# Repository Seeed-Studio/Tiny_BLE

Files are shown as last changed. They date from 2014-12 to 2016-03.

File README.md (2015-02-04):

Tiny BLE
==========

The Tiny BLE is a Bluetooth Low Energy development board designed with low energy consumption and small size in mind. It's integrated with current measurement feature to provide real time energy consumption data, which is essential for developers to optimize software to design long battery life devices. It supports ARM mbed cloud-based IDE with an handy C/C++ SDK and a large number of open source libraries, which makes prototyping and development extremely easy. Further, to keep it small, we use modular design to enable it divide into two parts - CMSIS DAP interface part and BLE part.

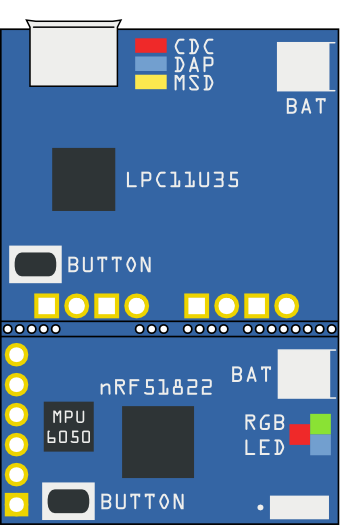
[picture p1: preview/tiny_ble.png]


----
### CMSIS DAP Interface Part
The interface is very powerful to provide features :

+ Drag-n-drop programming
+ CMSIS DAP debug
+ USB Virtual serial port
+ Current measurement
+ Battery charging

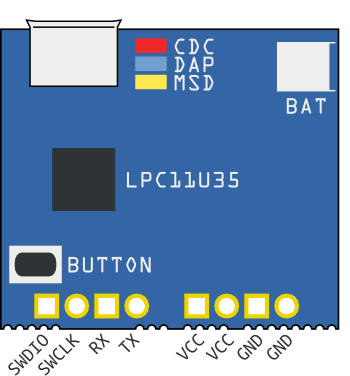
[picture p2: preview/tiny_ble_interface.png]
interface


To enable the current measurement feature, just set the baud rate of the USB virtual serial port to 4000000+, then the current data of the BLE part will be sent through the virtual serial port. To make data easier to use, we create a cross platform tool - BLE Smurfs Monitor to make it visual.

+ [Tiny BLE Monitor for Windows](http://tangram.qiniudn.com/ble_smurfs_monitor_v0.1.exe)
+ [Tiny BLE Monitor for Linux/Mac OS](https://github.com/Seeed-Studio/Tiny_BLE/tree/master/utils), additional requirements: pyqtgraph, pyside

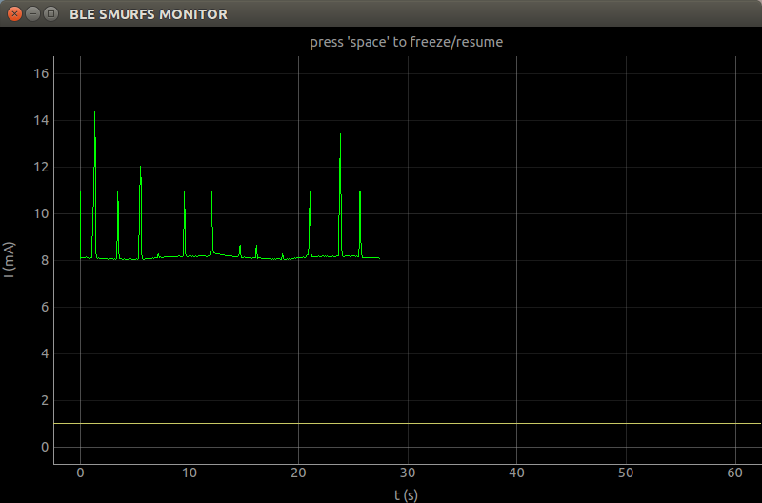
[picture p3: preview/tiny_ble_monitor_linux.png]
Tiny BLE Monitor


----

### BLE part

+ Nordic nRF51822 with BLE and ARM Cortex M0
+ MPU6050, 3d accelerometer and 3d gyroscope
+ RGB LED
+ Battery Connector & Battery Voltage Measurement
+ all 4 I/Os can be used as analog input, digital input/output, i2c, spi or uart

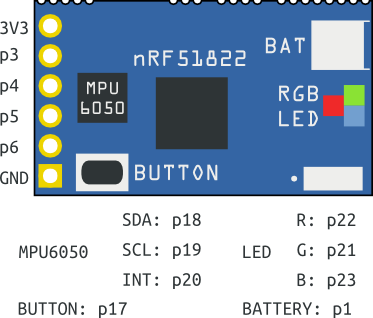
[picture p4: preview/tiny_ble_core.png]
ble part


The BLE part is built on the Nordic nRF51822 with Bluetooth Low Energy 2.4GHz multiprotocol radio and a 32 bit ARM Cortex-M0 core running 16MHz.
MPU6050, a 6 DOF with 3D accelerometer and 3D gyroscope, is integrated to provide motion detect feature. The Digital Motion Processor (DMP) of the MPU6050 provide several features (such as gesture detect, pedometer, calibrating gyro data) which
can reduce running time of the nRF51822 to get a long battery life. It also integrates battery connector and battery voltage measurement circuit for you.
We custom a bootloader for the BLE Smurfs to enable Firmware-Over-The-Air feature. when the BLE Smurfs is divided into two parts, we can still update the firmware of the nRF51822 through FOTA

Have fun!

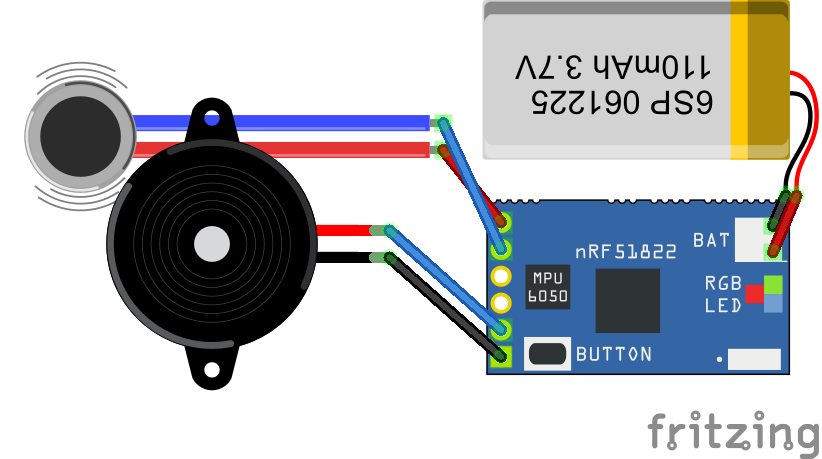
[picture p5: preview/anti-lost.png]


----

This software in this repository is written by [Seeedstudio](http://seeed.cc)<br>
and is licensed under [The Apache License V2.0](http://www.apache.org/licenses/LICENSE-2.0).

Contributing to this software is warmly welcomed. You can do this basically by<br>
[forking](https://help.github.com/articles/fork-a-repo), committing modifications and then [pulling requests](https://help.github.com/articles/using-pull-requests) (follow the links above<br>
for operating guide). Adding change log and your contact into file header is encouraged.<br>
Thanks for your contribution.

Seeed Studio is an open hardware facilitation company based in Shenzhen, China. <br>
Benefiting from local manufacture power and convenient global logistic system, <br>
we integrate resources to serve new era of innovation. Seeed also works with <br>
global distributors and partners to push open hardware movement.<br>

Analytics (https://github.com/igrigorik/ga-beacon)

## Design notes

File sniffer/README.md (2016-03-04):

Tiny BLE as a BLE Sniffer
=========================

1. Get nRF Sniffer resource from [Nordic Semiconductor](https://www.nordicsemi.com/eng/Products/Bluetooth-Smart-Bluetooth-low-energy/nRF-Sniffer)

2. download the firmware of nRF Sniffer into the Tiny BLE.

3. Replace the interface firmware of Tiny BLE  with the [usb_to_uart_firmware.bin](usb_to_uart_firmware.bin) file.

  As the USB virtual serial's performance of the default firmware is not good enough, we need replace a new firmware.

  a. hold the button of the Tiny BLE and plug it into your computer.
  b. replace the firmware.bin file of a disk named `CRP DISABLD` with the usb_to_uart_firmware.bin file. If Linux/Mac is used, use the`sudo dd if={/path/to/usb_to_uart_firmware.bin} of={/path/to/firmware.bin} conv=notrunc` command.
  c. re-plug it into the computer. If windows is used, install the usb_to_uart_driver.inf driver.

4. If windows is used, use the BLE Sniffer application from Nordic Semiconductor. If Mac OS X is used, [nrf-ble-sniffer-osx](https://sourceforge.net/projects/nrfblesnifferosx/) is good choice.

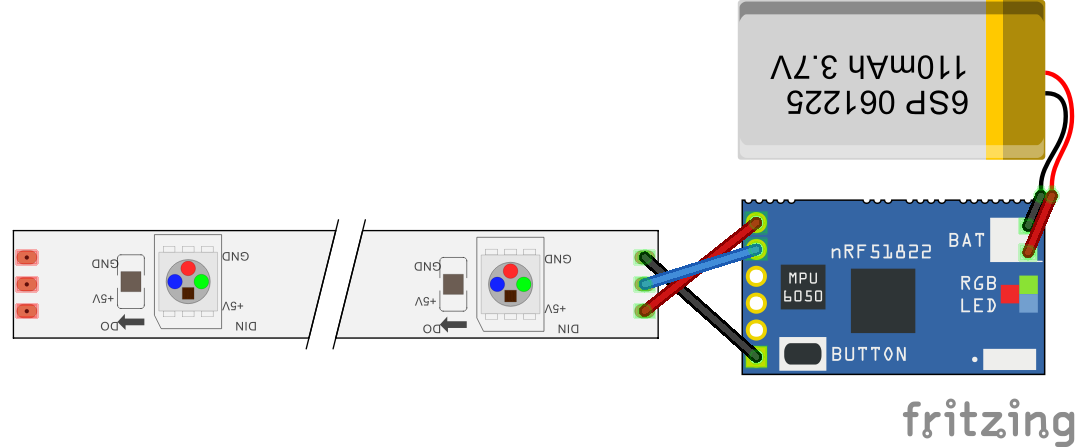
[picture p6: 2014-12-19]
preview/tiny_ble_color_pixels.png

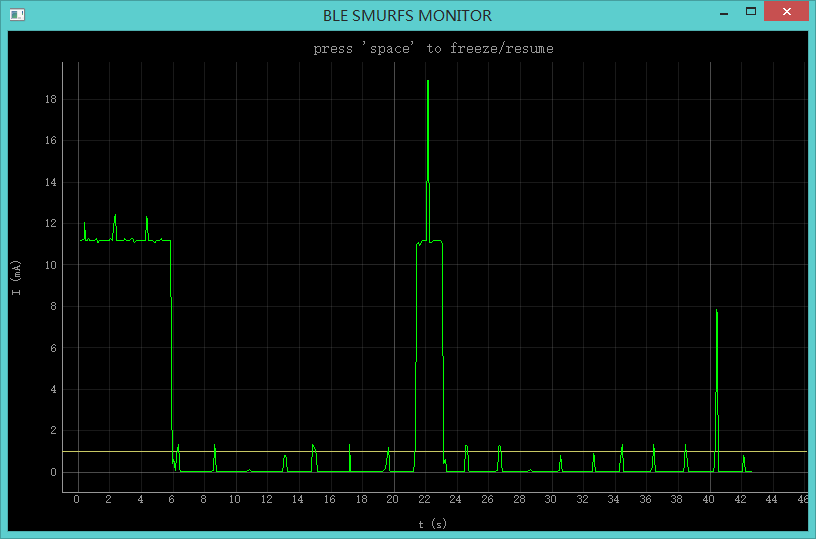
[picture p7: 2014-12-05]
preview/tiny_ble_monitor_windows.png

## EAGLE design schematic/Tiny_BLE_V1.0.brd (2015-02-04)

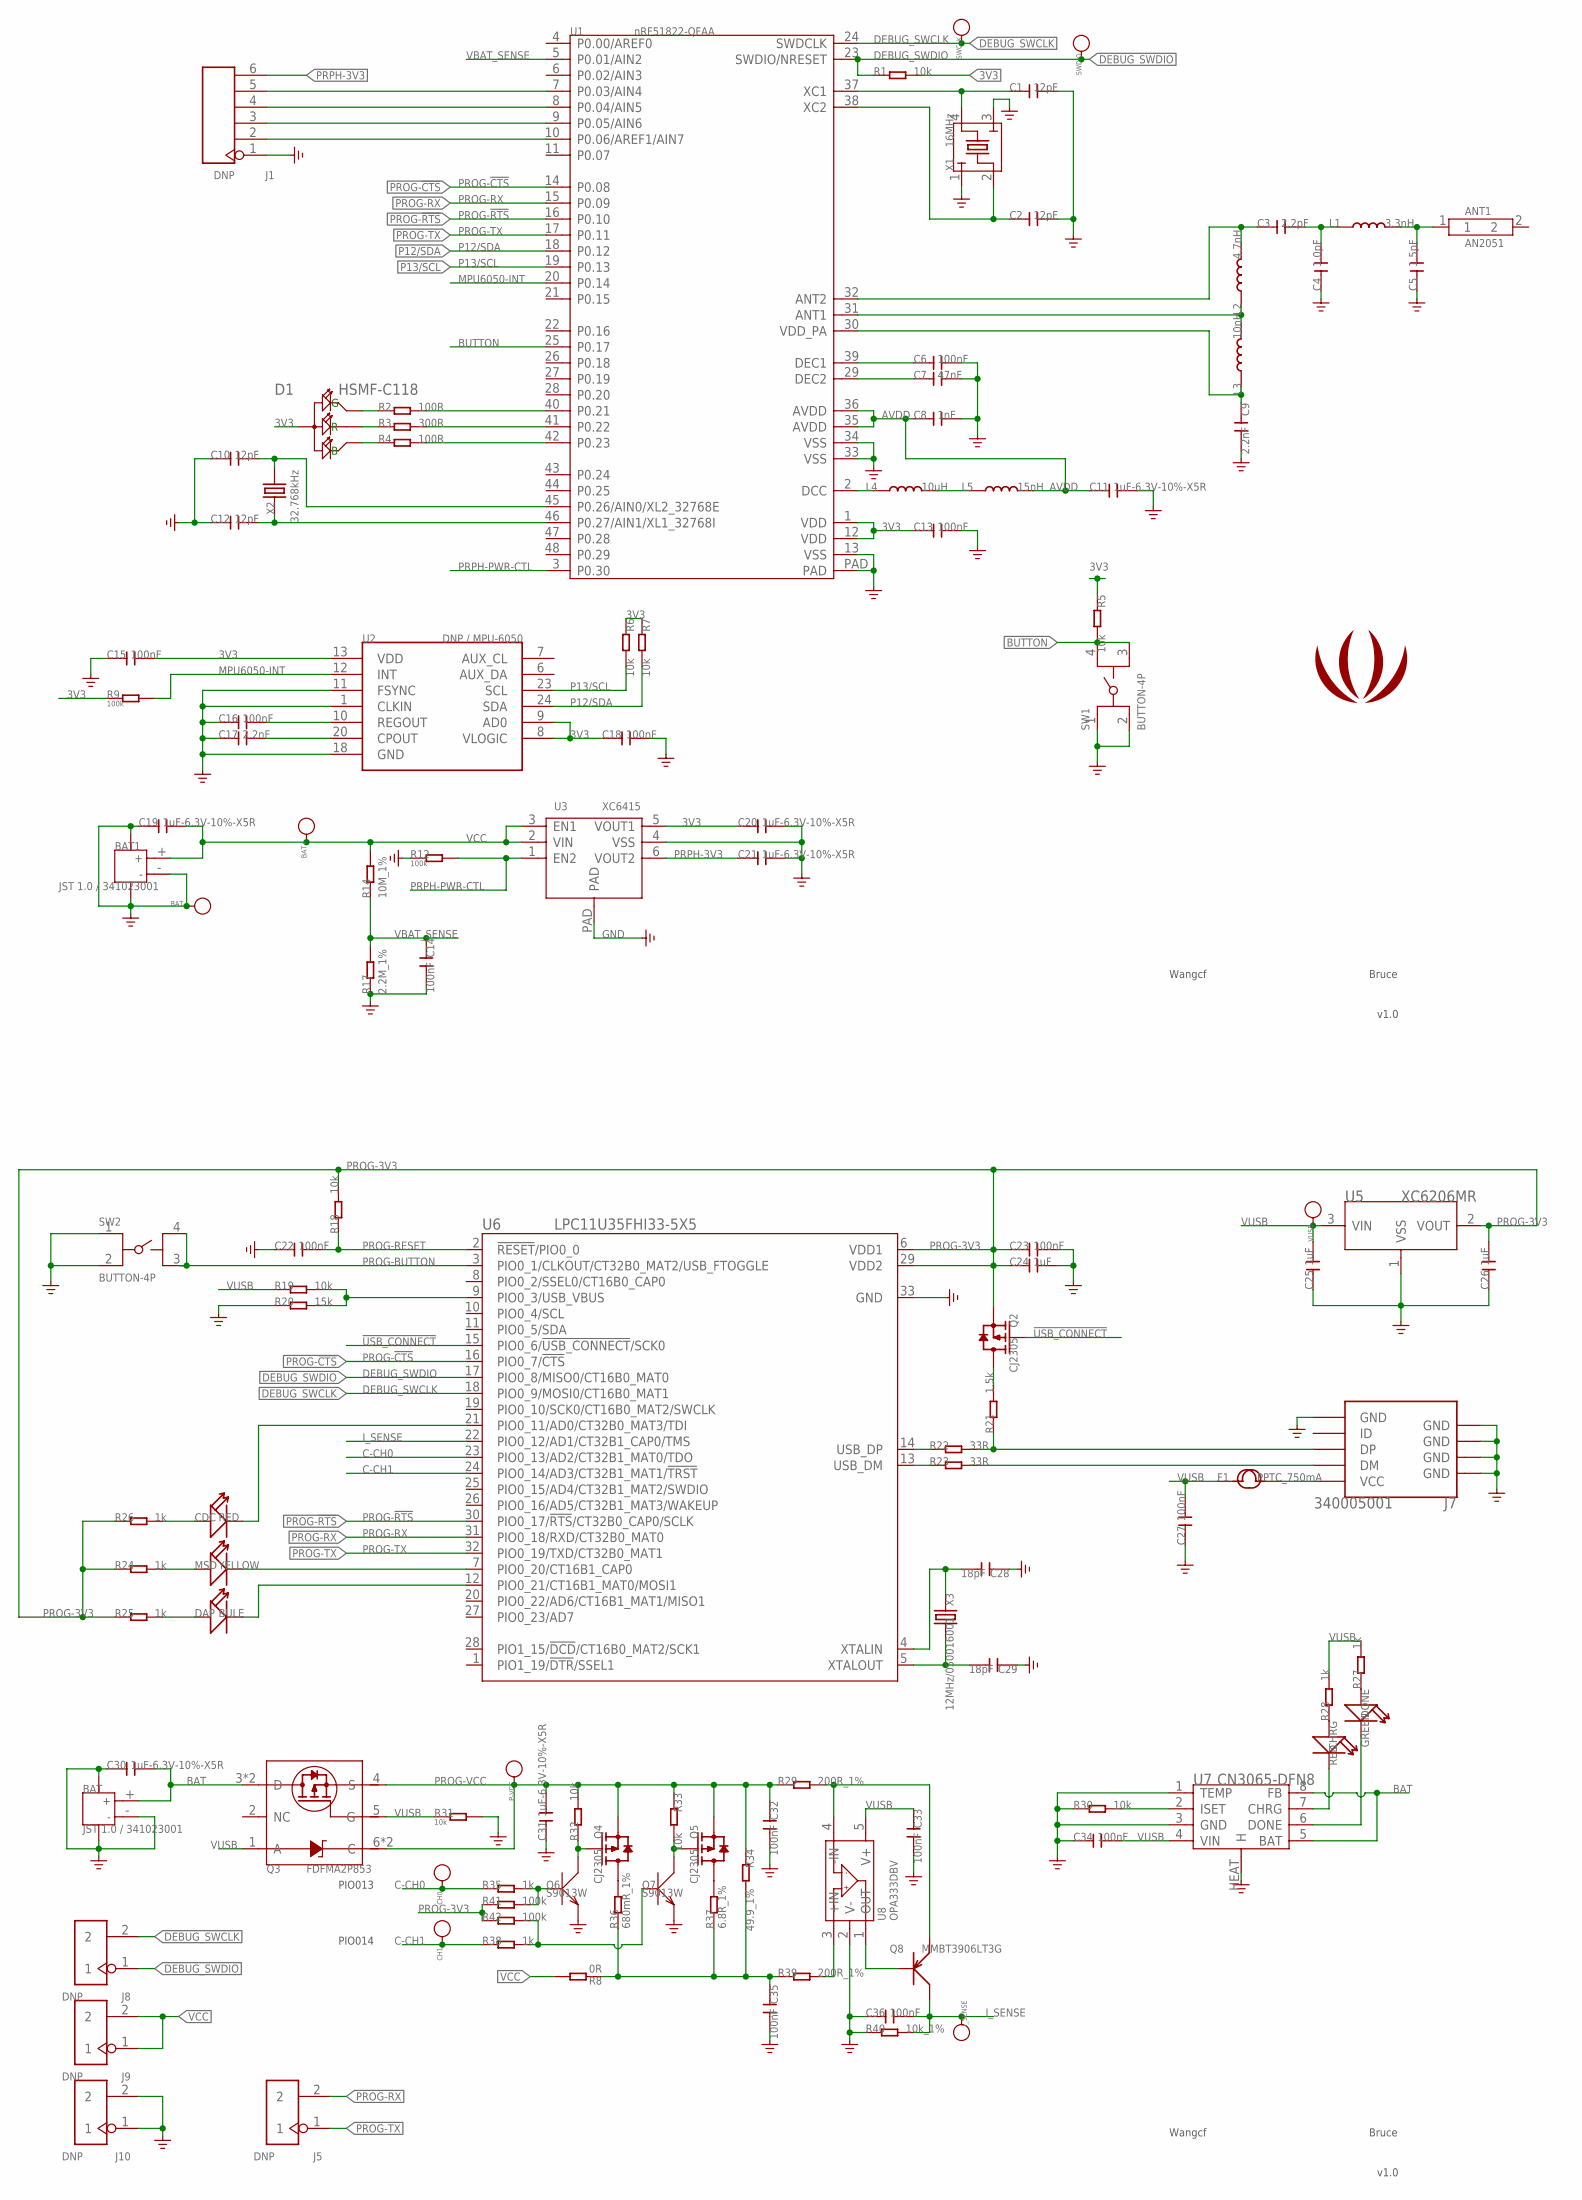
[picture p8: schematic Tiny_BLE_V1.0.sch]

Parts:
ANT1: AN2051; 2P-SMD-L5.05*W.02*H1.07MM
BAT, BAT1: JST 1.0 / 341023001; JST-SMD-2P-1.0-90D
BAT+: BAT+; PAD_4080
BAT-: BAT-; PAD_4080
C1, C2, C10, C12: 12pF; C0402
C3: 2.2pF; C0402
C4: 1.0pF; C0402
C5: 1.5pF; C0402
C6, C13, C14, C15, C16, C18, C22, C23, C27, C32, C33, C34, C35, C36: 100nF; C0402
C7: 47nF; C0402
C8: 1nF; C0402
C9, C17: 2.2nF; C0402
C11, C19, C20, C21, C30, C31: 1uF-6.3V-10%-X5R; C0402
C24, C25, C26: 1uF; C0402
C28, C29: 18pF; C0402
CDC: RED; LED-0603
CH0: CH0; TP_4545
CH1: CH1; TP_4545
CHRG: RED; LED-0603
D1: HSMF-C118; LED-4P-1210-3.0X2.54
DAP: BULE; LED-0603
DONE: GREEN; LED-0603
F1: PPTC_750mA; F1206
I_SENSE: I_SENSE; TP_4545
J1: DNP; 6P-2.54-60/35MIL
J5, J8, J9, J10: DNP; 2P-2.54-65/35MIL
J7: 340005001; MICRO-USB
L1: 3.3nH; L0402
L2: 4.7nH; L0402
L3: 10nH; L0402
L4: 10uH; L0603
L5: 15nH; L0402
MSD: YELLOW; LED-0603
P-VCC: P_VCC; TP_4545
Q2, Q4, Q5: CJ2305; SOT23
Q3: FDFMA2P853; 6P-SMD-W/-HEAT
Q6, Q7: S9013W; SOT323
Q8: MMBT3906LT3G; SOT23
R1, R5, R6, R7, R18, R19, R30, R31, R32, R33: 10k; R0402
R2, R4: 100R; R0402
R3: 300R; R0402
R8: 0R; R0603
R9, R12, R41, R42: 100k; R0402
R14: 10M_1%; R0402
R17: 2.2M_1%; R0402
R20: 15k; R0402
R21: 1.5k; R0402
R22, R23: 33R; R0402
R24, R25, R26, R27, R28, R35, R38: 1k; R0402
R29, R39: 200R_1%; R0402
R34: 49.9_1%; R0603
R36: 680mR_1%; R0603
R37: 6.8R_1%; R0603
R40: 10k_1%; R0402
SW1, SW2: BUTTON-4P; 4P-SMD-L4.45*W3.22*H2.5MM
SWCLK: SWDCLK; PAD_4080
SWDIO: SWDIO; PAD_4080
U1: nRF51822-QFAA; QFN48-6X6MM
U2: DNP / MPU-6050; QFN24
U3: XC6415; USP-6C
U5: XC6206MR; SOT23
U6: LPC11U35FHI33-5X5; HVQFN33
U7: CN3065-DFN8; DFN8
U8: OPA333DBV; SOT23-5
U$59: LOGO-SEEEDSTUDIO-SMALL-SILK; SMALL_SEEED_LOGO
VUSB: VUSB; TP_4545
X1: 16MHz; 2520
X2: 32.768kHz; 2P-SMD-3.2X1.5
X3: 12MHz/050016001; 2P-SMD-5X3.2

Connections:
3V3: C13.1, C15.2, C18.1, C20.1, D1.1 (+), R1.2, R5.1, R6.1, R7.1, R9.1, U1.1 (VDD), U1.12 (VDD), U2.8 (VLOGIC), U2.9 (AD0), U2.13 (VDD), U3.5 (VOUT1)
!USB_CONNECT: Q2.1 (G), U6.15 (PIO0_6/!USB_CONNECT!/SCK0)
AVDD: C8.1, C11.1, L5.2, U1.35 (AVDD), U1.36 (AVDD)
BAT: BAT.+ (1), C30.2, Q3.3 (D), Q3.P2 (D), U7.5 (BAT), U7.8 (FB)
BUTTON: R5.2, SW1.3, SW1.4, U1.25 (P0.17)
C-CH0: CH0.T, R35.1, U6.23 (PIO0_13/AD2/CT32B1_MAT0/TDO)
C-CH1: CH1.T, R38.1, U6.24 (PIO0_14/AD3/CT32B1_MAT1/!TRST!)
CHRG: CHRG.-, U7.7 (CHRG)
CHRG-DONE: DONE.-, U7.6 (DONE)
DCC: L4.1, U1.2 (DCC)
DEBUG_SWCLK: J8.2, SWCLK.1, U1.24 (SWDCLK), U6.18 (PIO0_9/MOSI0/CT16B0_MAT1)
DEBUG_SWDIO: J8.1, R1.1, SWDIO.1, U1.23 (SWDIO/NRESET), U6.17 (PIO0_8/MISO0/CT16B0_MAT0)
GND: BAT.3, BAT.4, BAT.- (2), BAT1.3, BAT1.4, BAT1.- (2), BAT-.1, C1.2, C2.2, C4.1, C5.1, C6.2, C7.2, C8.2, C9.2, C10.1, C11.2, C12.1, C13.2, C14.2, C15.1, C16.1, C17.1, C18.2, C19.1, C20.2, C21.2, C22.1, C23.2, C24.2, C25.1, C26.1, C27.1, C28.1, C29.1, C30.1, C31.1, C32.2, C33.2, C34.1, C35.2, C36.1, J1.1, J7.5 (GND), J7.S1 (GND), J7.S2 (GND), J7.S3 (GND), J7.S4 (GND), J7.S5 (GND), J7.S6 (GND), J10.1, J10.2, Q6.2 (E), Q7.2 (E), R12.1, R17.1, R20.1, R30.1, R31.2, R40.1, SW1.1, SW1.2, SW2.1, SW2.2, U1.13 (VSS), U1.33 (VSS), U1.34 (VSS), U1.PAD, U2.1 (CLKIN), U2.11 (FSYNC), U2.18 (GND), U3.4 (VSS), U3.PAD, U5.1 (VSS), U6.33 (GND), U7.1 (TEMP), U7.3 (GND), U7.HEAT (H), U8.2 (V-), X1.1, X1.3
ISET: R30.2, U7.2 (ISET)
I_SENSE: C36.2, I_SENSE.T, Q8.3 (C), R40.2, U6.22 (PIO0_12/AD1/CT32B1_CAP0/TMS)
MPU6050-INT: R9.2, U1.20 (P0.14), U2.12 (INT)
unnamed: Q8.2 (E), R29.2, U8.4 (-IN)
unnamed: C29.2, U6.5 (XTALOUT), X3.2
unnamed: D1.3 (G), R2.1
unnamed: C28.2, U6.4 (XTALIN), X3.1
unnamed: D1.2 (R), R3.1
unnamed: R22.1, U6.14 (USB_DP)
unnamed: R23.1, U6.13 (USB_DM)
unnamed: J7.3 (DP), R21.1, R22.2
unnamed: Q4.1 (G), Q6.3 (C), R32.1
unnamed: J7.2 (DM), R23.2
unnamed: C10.2, U1.45 (P0.26/AIN0/XL2_32768E), X2.2
unnamed: C12.2, U1.46 (P0.27/AIN1/XL1_32768I), X2.1
unnamed: C1.1, U1.37 (XC1), X1.4
unnamed: C2.1, U1.38 (XC2), X1.2
unnamed: CDC.-, U6.21 (PIO0_11/AD0/CT32B0_MAT3/TDI)
unnamed: C16.2, U2.10 (REGOUT)
unnamed: C6.1, U1.39 (DEC1)
unnamed: C17.2, U2.20 (CPOUT)
unnamed: C7.1, U1.29 (DEC2)
unnamed: C3.1, L2.2, U1.32 (ANT2)
unnamed: L2.1, L3.2, U1.31 (ANT1)
unnamed: C9.1, L3.1, U1.30 (VDD_PA)
unnamed: C3.2, C4.2, L1.1
unnamed: ANT1.1, C5.2, L1.2
unnamed: L4.2, L5.1
unnamed: Q2.3 (D), R21.2
unnamed: F1.2, J7.1 (VCC)
unnamed: R19.2, R20.2, U6.9 (PIO0_3/USB_VBUS)
unnamed: CDC.+, R26.2
unnamed: DAP.+, R25.2
unnamed: MSD.+, R24.2
unnamed: MSD.-, U6.7 (PIO0_20/CT16B1_CAP0)
unnamed: DAP.-, U6.12 (PIO0_21/CT16B1_MAT0/MOSI1)
unnamed: D1.4 (B), R4.1
unnamed: Q8.1 (B), U8.1 (OUT)
unnamed: R39.2, U8.3 (+IN)
unnamed: Q5.3 (D), R37.2
unnamed: Q4.3 (D), R36.2
unnamed: Q6.1 (B), R35.2, R41.2
unnamed: Q5.1 (G), Q7.3 (C), R33.2
unnamed: Q7.1 (B), R38.2, R42.2
unnamed: DONE.+, R27.1
unnamed: CHRG.+, R28.1
unnamed: R2.2, U1.40 (P0.21)
unnamed: R3.2, U1.41 (P0.22)
unnamed: R4.2, U1.42 (P0.23)
unnamed: J1.2, U1.10 (P0.06/AREF1/AIN7)
unnamed: J1.3, U1.9 (P0.05/AIN6)
unnamed: J1.4, U1.8 (P0.04/AIN5)
unnamed: J1.5, U1.7 (P0.03/AIN4)
unnamed: C35.1, R8.1, R34.2, R36.1, R37.1, R39.1
P12/SDA: R7.2, U1.18 (P0.12), U2.24 (SDA)
P13/SCL: R6.2, U1.19 (P0.13), U2.23 (SCL)
PROG-3V3: C23.1, C24.1, C26.2, Q2.2 (S), R18.2, R24.1, R25.1, R26.1, R41.1, R42.1, U5.2 (VOUT), U6.6 (VDD1), U6.29 (VDD2)
PROG-!CTS: U1.14 (P0.08), U6.16 (PIO0_7/!CTS!)
PROG-!RTS: U1.16 (P0.10), U6.30 (PIO0_17/!RTS!/CT32B0_CAP0/SCLK)
PROG-BUTTON: SW2.3, SW2.4, U6.3 (PIO0_1/CLKOUT/CT32B0_MAT2/USB_FTOGGLE)
PROG-RESET: C22.2, R18.1, U6.2 (!RESET!/PIO0_0)
PROG-RX: J5.2, U1.15 (P0.09), U6.31 (PIO0_18/RXD/CT32B0_MAT0)
PROG-TX: J5.1, U1.17 (P0.11), U6.32 (PIO0_19/TXD/CT32B0_MAT1)
PROG-VCC: C31.2, C32.1, P-VCC.T, Q3.4 (S), Q3.6 (C), Q3.P1 (C), Q4.2 (S), Q5.2 (S), R29.1, R32.2, R33.1, R34.1
PRPH-3V3: C21.1, J1.6, U3.6 (VOUT2)
PRPH-PWR-CTL: R12.2, U1.3 (P0.30), U3.1 (EN2)
VBAT_SENSE: C14.1, R14.1, R17.2, U1.5 (P0.01/AIN2)
VCC: BAT1.+ (1), BAT+.1, C19.2, J9.1, J9.2, R8.2, R14.2, U3.2 (VIN), U3.3 (EN1)
VUSB: C25.2, C27.2, C33.1, C34.2, F1.1, Q3.1 (A), Q3.5 (G), R19.1, R27.2, R28.2, R31.1, U5.3 (VIN), U7.4 (VIN), U8.5 (V+), VUSB.T

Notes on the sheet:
Wangcf
PIO014
PIO013
Bruce
v1.0

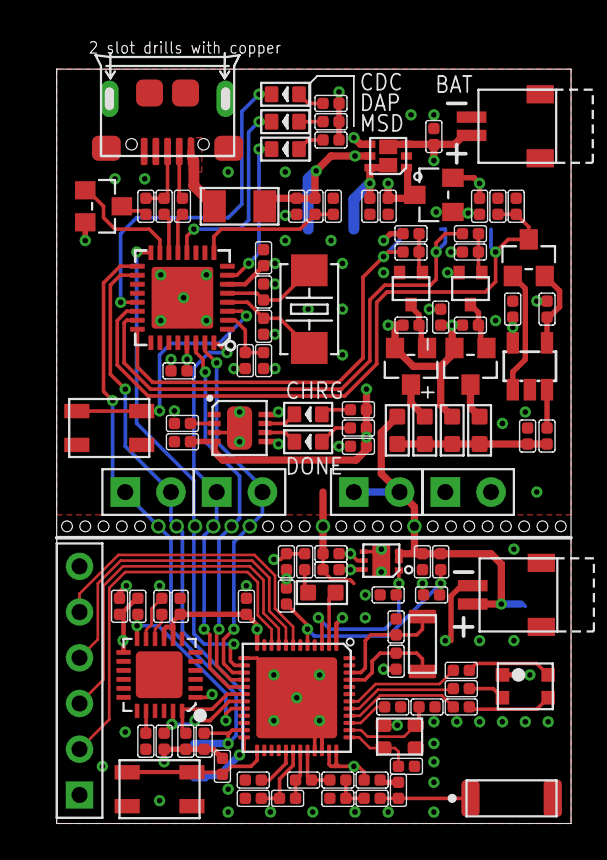
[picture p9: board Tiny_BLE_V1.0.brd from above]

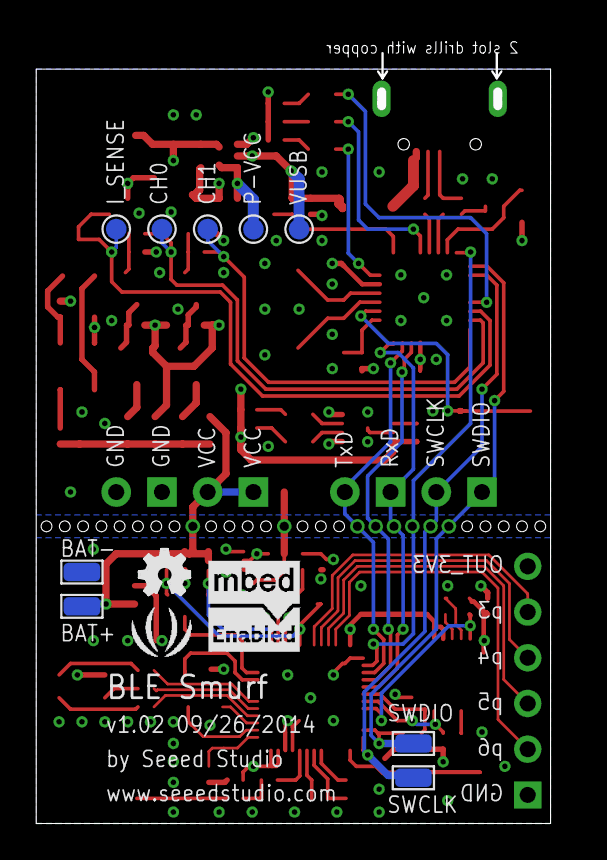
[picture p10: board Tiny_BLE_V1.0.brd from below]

Board: 4 copper layers, 28.6 x 42.8 mm, 124 parts (11 on the bottom side), 82 nets.

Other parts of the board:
U$30: OSHW_FILLX100_NOTEXT

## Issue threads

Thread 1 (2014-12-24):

Hi.where can i Buy this board.

giohomer, 2014-12-24:
Hi where can i buy this board?
and where can i find the firmware?
I'm a student and i need to work with nrf51822 and MPU6050.
I have the nordic dev kit but i have some problem to work with TWI and soft device. Can you help me?

xiongyihui, 2015-02-26:
Hi, the board is available at http://www.seeedstudio.com/depot/Seeed-Tiny-BLE-BLE-6DOF-Mbed-Platform-p-2268.html now. You can try the MPU6050 library - http://developer.mbed.org/teams/Seeed/code/eMPL_MPU6050/  we used.

Closed 2015-02-26.

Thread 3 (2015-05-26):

Extra pinouts

pandzorz, 2015-05-26:
Hello,

I am working on a project at university, using a Tiny BLE board. I have been trying to find a clock output for use with a W25Q80BV as the serial clock, but unsure where I can pull this from on the board(e.g. SWCLK) and how to address that pin in my code.

Regards,
Andrew

xiongyihui, 2015-05-27:
Unfortunately, the SWCLK can not be used as GPIO.
We are considering to design a new version of the Tiny BLE. It would be great to know your feedback of it.

pandzorz, 2015-05-27:
Thanks for your reply. I feel that only 4 GPIO pins has been limiting for our project, and the ability to access the chip's clock value for serial clock syncing has been an issue as well, so they would be great to see on the chip. Additionally, more information for the pin names would be great, I had to look deep into the code to find the enum values for the board.

We're trying to use a 1MB flash storage chip over MISO/MOSI, but need a clock value from the chip. Is this possible at all? I've been trying to find somewhere in the schematic and board diagrams for this potential. Thanks for your time!

xiongyihui, 2015-05-27:
Thanks for your feedback.
The pin information is as following.
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
The 4 available pins are p3-p6, all these pins can be used for analog, i2c or spi.
For example, p3 - miso, p4 - mosi, p5 -sck. The feature is IO flexible mapping.

Closed 2015-08-04.

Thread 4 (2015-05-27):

Split board

Kazjako, 2015-05-27:
Hi,

I just receivied the TinyBLE i bought and i thought it would be splitted in two parts. I would like to test just the BLE part to test the antenna range. Could you please tell me the best way to do it? I mean how to split it and then beeing able to reunite to program it.

And a second thing. The current measurement can work alone in the BLE part?

Thank you,

qunanan, 2015-06-01:
I think the simple way is you just split it .    : P

xiongyihui, 2015-06-02:
1. Before splitting it, you'd better to program an OTA bootloader to the BLE part. See [nRF51 DFU bootloader](https://github.com/Seeed-Studio/nrf51_dfu_bootloader) and [nRF51822 OTA](https://developer.mbed.org/teams/Bluetooth-Low-Energy/wiki/Firmware-Over-the-Air-FOTA-Updates).

The SWDIO and SWCLK on the back of the BLE part can be also used to program it.

2. Yes, the CMSIS DAP interface part can be used standalone.

Closed 2015-06-02.

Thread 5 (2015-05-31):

BLE part Battery

Kazjako, 2015-05-31:
Hi,
I have some questions that i cannot find.
First question, Is the battery in the BLE part rechargeable?
Second question, i have been trying to enable the 3v3 pin in the BLE part. Following the schematic i found that the pin to activate would be the P30 in the nordic chip, am i right?
Third question. Following the Tiny BLE example code in mbed, it is supposed that when i press the BLE button SW1 (p17 in nordic chip) the blue led is supposed to blink, but actually, it only blinks when i press the SW2, the button that is in the CMSIS part, why?

Thank you,

xiongyihui, 2015-06-02:
Hi Kazjako,

1. By default, the Tiny BLE doesn't contain a battery. It has a JST-1.0 battery connector.
2. Yes, the 3v3 pin is controlled by p30
3. pressing SW2 will reset the nordic chip, the SW1 button function is defined by your program.

Kazjako, 2015-06-17:
Hi xingyihui,
I did some small modification of the tiny BLE and i wanted to assambly them using your seeed services. But i found that the following components are not included in the OPL list. Do you recommend something to assembly? Or could you add these components into the OPL list so we should be able do our own modification? The components not included in the OPL list are:
1	16MHz CRYSTAL'-2520'	2520	X1
1	 AN2051 ANTENNA-2.4GHZ-0.5DBI'AN2051'	2P-SMD-L5.05*W.02*H1.07MM AN2051	 ANT1
1	HSMF-C118 LED-ARGB-4P-1210 	LED-4P-1210-3.0X2.54	D1
1	XC6415 XC6415 USP-6C U3 Dual LDO Regulator with ON/OFF Switch 2 200R_1%	R-0402 	  R29, R39
1	 6.8R_1%	R-0603 R0603	R37
1	680mR_1%	R-0603 R0603	R36
1	BUTTON-4P	4P-SMD-L4.45*W3.22*H2.5MM	SW2
1	FDFMA2P853 FDFMA2P853	 6P-SMD-W/-HEAT	 Q3
1	JST 1.0 / 341023001	JACK-JST-2P-SMD-PW'1.0' JST-SMD-2P-1.0-90D	BAT
1	340005001	USB-MINIUSB-5P-MICRO MICRO-USB	J7

xiongyihui, 2015-06-18:
It will be ok if these components are not in the OPL list. Please feel free to contact [us](producer@seeed.cc)

Closed 2015-08-04.

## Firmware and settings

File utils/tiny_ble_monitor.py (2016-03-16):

#!/usr/bin/env python
# -*- coding: utf-8 -*-
"""
BLE SMURFS MONITOR
Plot realtime power comsumption of BLE SMURFS
"""

import sys
import serial
from serial.tools import list_ports
from PySide.QtCore import QThread, Signal, Slot, Qt
from PySide.QtGui import QApplication, QMainWindow, QWidget, QHBoxLayout, QMessageBox, QKeyEvent
import pyqtgraph as pg
import numpy as np

data = np.empty(1000)
data_index = 0

class SerialThread(QThread):
    error = Signal(int)
    
    def __init__(self, parent=None):
        QThread.__init__(self, parent)
        self.exit = False
        
    def run(self):
        global data, data_index

        print('--- serial thread started ---')
        port = None
        for p in list_ports.comports():
            print(p)
            if p[2].upper().startswith('USB VID:PID=0D28:0204') or p[2].upper().startswith('USB VID:PID=D28:204'):
                port = p[0]
                break
                
        if not port:
            print('no device available')
            self.error.emit(1)
            return
            
        print('open %s' % port)
        device = serial.Serial(port=port,
                               baudrate=4000000,
                               bytesize=8,
                               parity='N',
                               stopbits=1,
                               timeout=1)
        while not self.exit:
            try:
                line = device.readline()
                data[data_index] = int(line) / 1000.0  # uA to mA
                data_index += 1
                if data_index >= data.shape[0]:
                    tmp = data
                    data = np.empty(data.shape[0] * 2)
                    data[:tmp.shape[0]] = tmp
            except IOError as e:
                print('io error: %s', e)
                self.error.emit(2)
                break
            except ValueError:
                print('invalid line')
                
        device.close()
        print('--- serial thread finished')

class MainWindow(QMainWindow):
    def __init__(self, parent=None):
        super(MainWindow, self).__init__(parent)
        self.setWindowTitle('Tiny BLE Monitor')
        self.resize(800, 500)
        self.cwidget = QWidget()
        self.setCentralWidget(self.cwidget)
        layout = QHBoxLayout()
        layout.setContentsMargins(0, 0, 0, 0)
        self.cwidget.setLayout(layout)
        self.pwidget = pg.PlotWidget()
        layout.addWidget(self.pwidget)
        
        self.pwidget.setTitle(title="press 'space' to freeze/resume")
        self.pwidget.setLabel('left', 'I', units='mA')
        self.pwidget.setLabel('bottom', 't')
        self.pwidget.showButtons()
        self.pwidget.setXRange(0, 3000)
        self.pwidget.setYRange(0, 16)
        # self.pwidget.enableAutoRange(axis=pg.ViewBox.YAxis)
        line = pg.InfiniteLine(pos=1.0, angle=0, movable=True, bounds=[0, 200])
        self.pwidget.addItem(line)
        self.pwidget.showGrid(x=True, y=True, alpha=0.5)
        self.plot = self.pwidget.plot()
        self.plot.setPen((0, 255, 0))
        
        # plotitem = self.pwidget.getPlotItem()
        # plotitem.setLimits(xMin=-1, yMin=-1, minXRange=-1, minYRange=-1) # require pyqtgraph 0.9.9+
        
        self.thread = SerialThread()
        self.thread.error.connect(self.handle_error)
        self.thread.start()
        self.freeze = False
        self.timer = pg.QtCore.QTimer()
        self.timer.timeout.connect(self.update)
        self.timer.start(50)
        
    @Slot(int)
    def handle_error(self, error):
        flags = QMessageBox.Abort | QMessageBox.StandardButton.Retry
        message = 'No device available!'
        if error > 1:
            message = 'Failed to read data!'
            
        result = QMessageBox.critical(self, 'ERROR', message, flags)
        if result == QMessageBox.StandardButton.Retry:
            self.thread.start()
        else:
            self.close()

    def update(self):
        global data, data_index

        if not self.freeze:
            r = self.pwidget.viewRange()
            if data_index >= r[0][1]:
                self.pwidget.setXRange(data_index, data_index + r[0][1] - r[0][0])
            self.plot.setData(data[:data_index])
        
    def keyPressEvent(self, event):
        key = event.key()
        if key == Qt.Key_Escape:
            self.pwidget.setXRange(0, data_index + 1000)
            self.pwidget.enableAutoRange(axis=pg.ViewBox.YAxis)
        elif key == Qt.Key_Space:
            self.freeze = not self.freeze
            
        return True
        
    def closeEvent(self, event):
        if self.thread.isRunning():
            self.thread.exit = True
            while self.thread.isRunning():
                pass

        event.accept()

if __name__ == '__main__':
    app = QApplication([])
    window = MainWindow()
    window.show()
    app.exec_()

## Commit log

2015-02-04 change name and add schematic
    [Tiny_BLE_V1.0.brd, Tiny_BLE_V1.0.sch]
2015-03-05 Fix for OSX USB serial detection
    [tiny_ble_monitor.py]
